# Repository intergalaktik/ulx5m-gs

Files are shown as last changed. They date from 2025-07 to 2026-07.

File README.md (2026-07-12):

# Work in progress!!! 

# Please use v005

# Please check the list of confirmed working

# DEFAULT VOLTAGE FOR GPIO IS SET TO 1.8V!!!

# DEFAULT SDRAM PART is 1.8V

# DEFAULT VCC CORE is 0.9V - if you use SerDes this needs to be higher

# Most of our tests are done with VCC CORE 1.1V 

# ULX5M-GS v005
ULX5M with GateMate with SDRAM

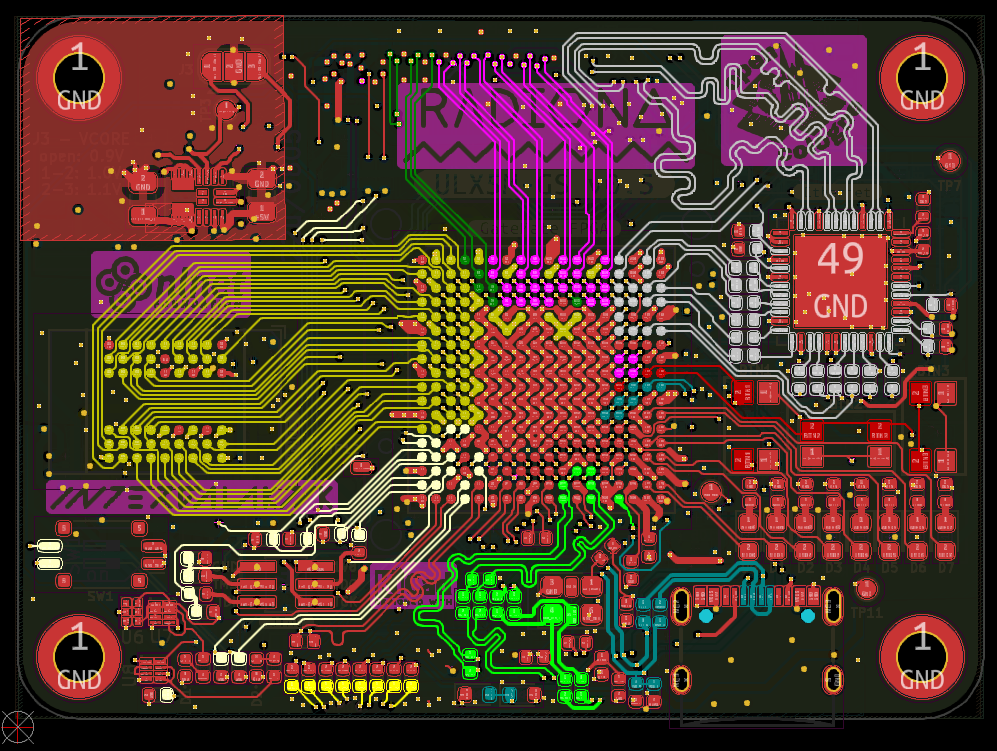
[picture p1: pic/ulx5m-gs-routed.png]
Layers_v001

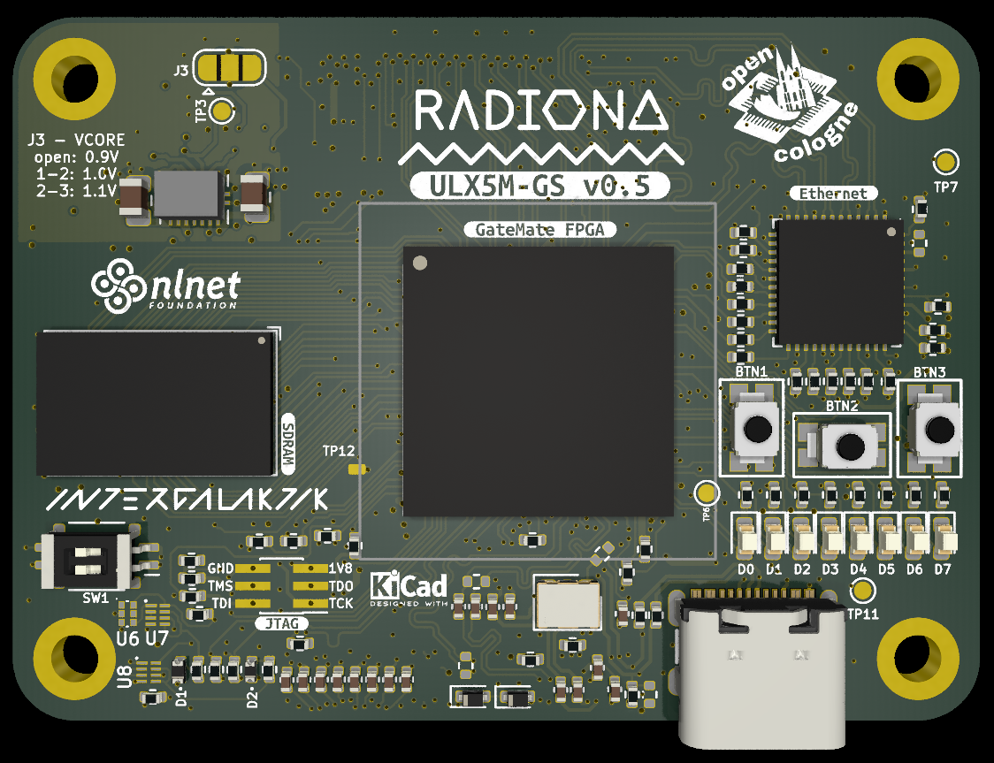
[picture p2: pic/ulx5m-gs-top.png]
TOP

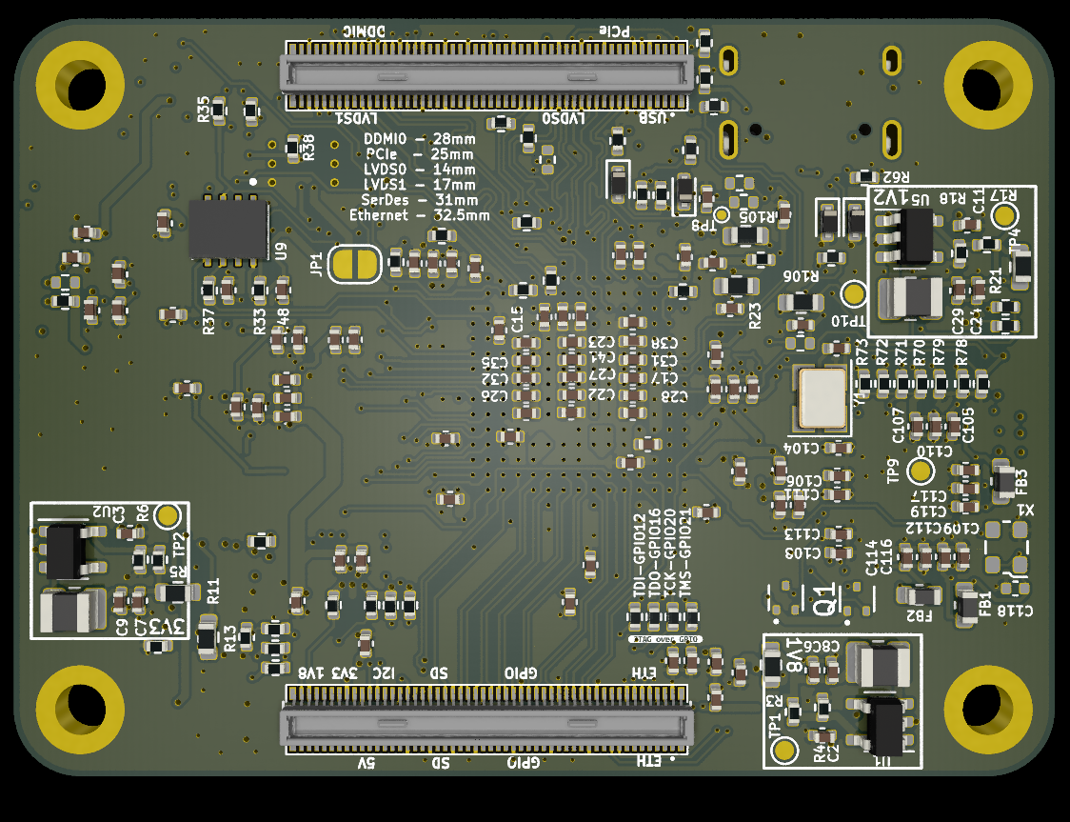
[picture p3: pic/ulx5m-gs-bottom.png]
BOTTOM


#### ULX5M-GS V001

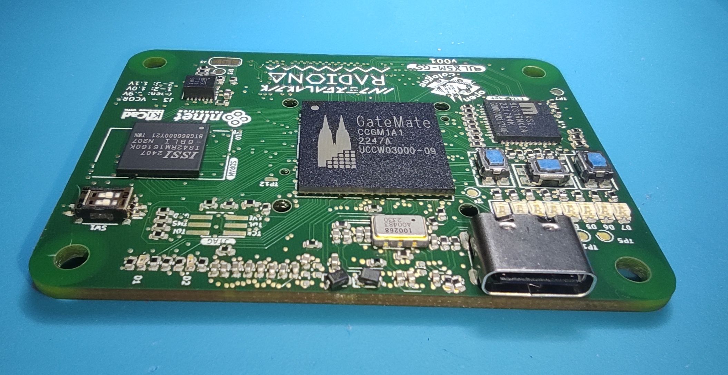
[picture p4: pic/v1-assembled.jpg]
Assembled


#### V001 LED ON

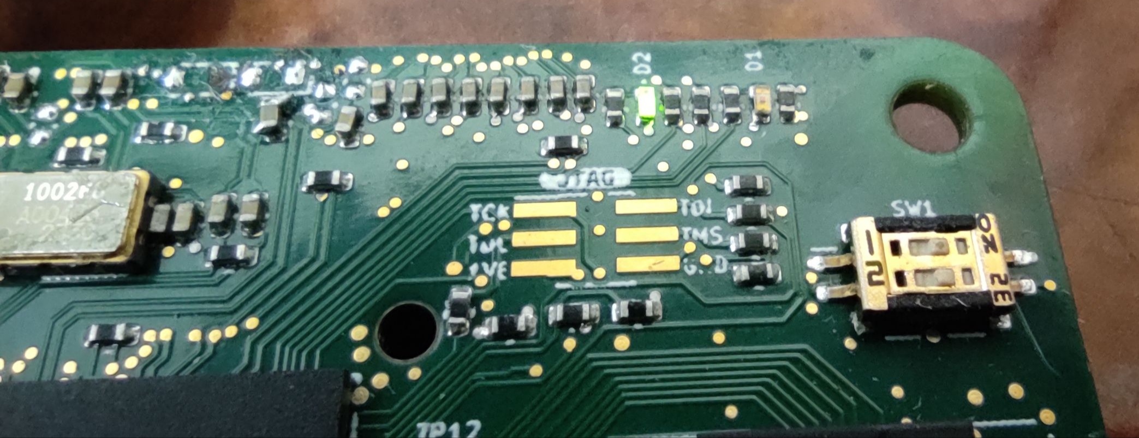
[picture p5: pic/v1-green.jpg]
Green


#### ULX5M-v02 bringup

#### Blink LED

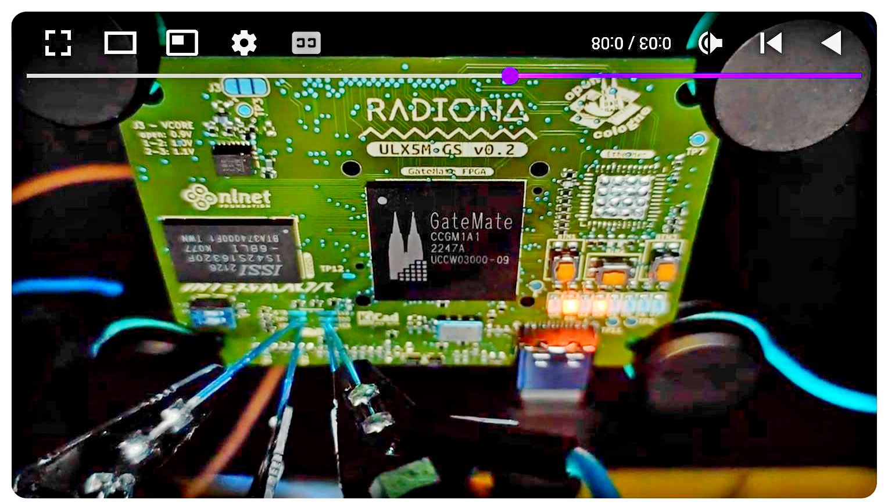
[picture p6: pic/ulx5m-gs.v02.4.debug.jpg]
ULX5M blinks LEDs on its own (https://www.youtube.com/watch?v=LA20pfW7X00 "ULX5M is counting!")


#### DVI OUT

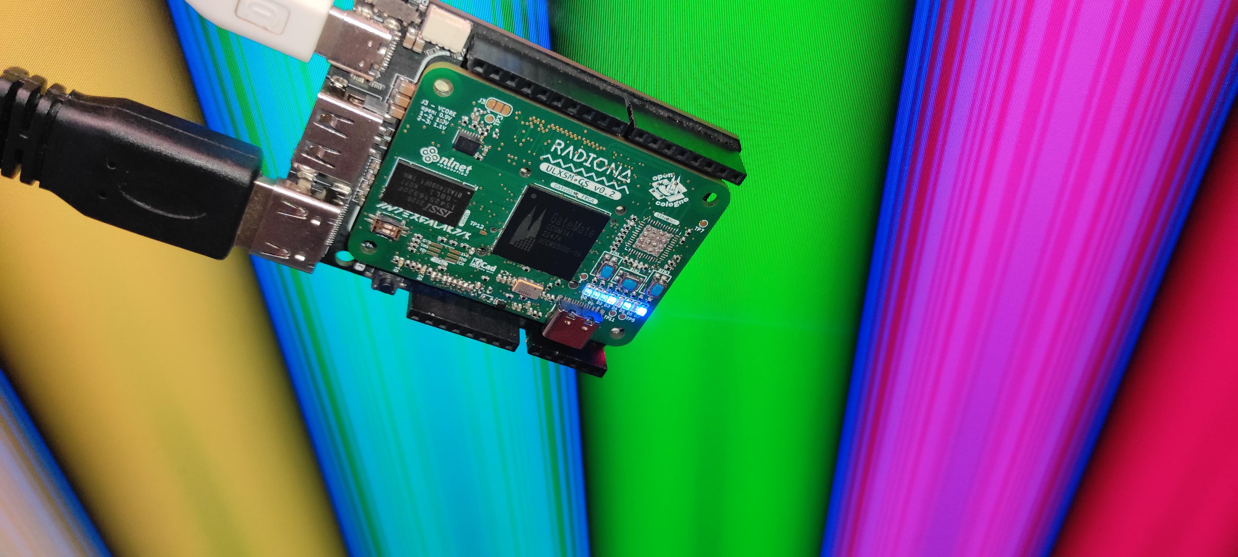
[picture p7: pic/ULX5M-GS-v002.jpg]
V002


#### SDRAM working with LiteX

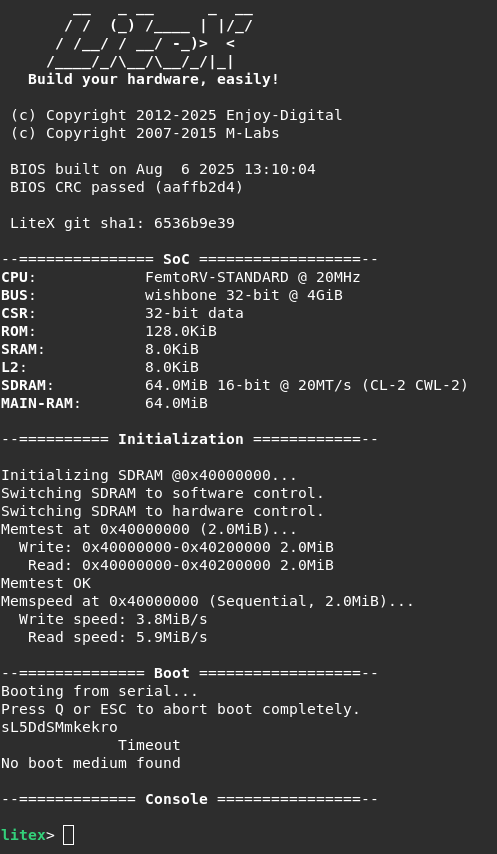
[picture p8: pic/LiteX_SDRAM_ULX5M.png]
V002 Litex


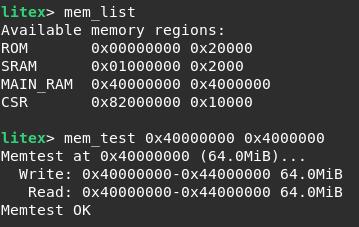
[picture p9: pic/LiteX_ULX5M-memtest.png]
V002 Litex full memtest


#### VGA over GPIO

While testing LVDS I wanted to check if we can have VGA over GPIO and it looks OK 

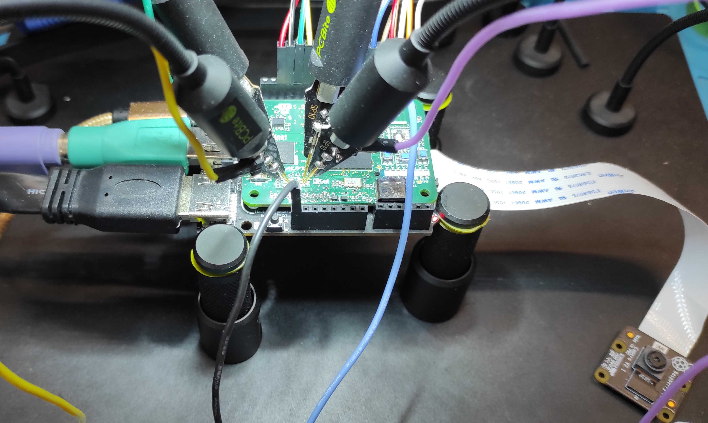
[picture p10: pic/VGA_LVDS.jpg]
V002 VGA


For now only possible over VGA

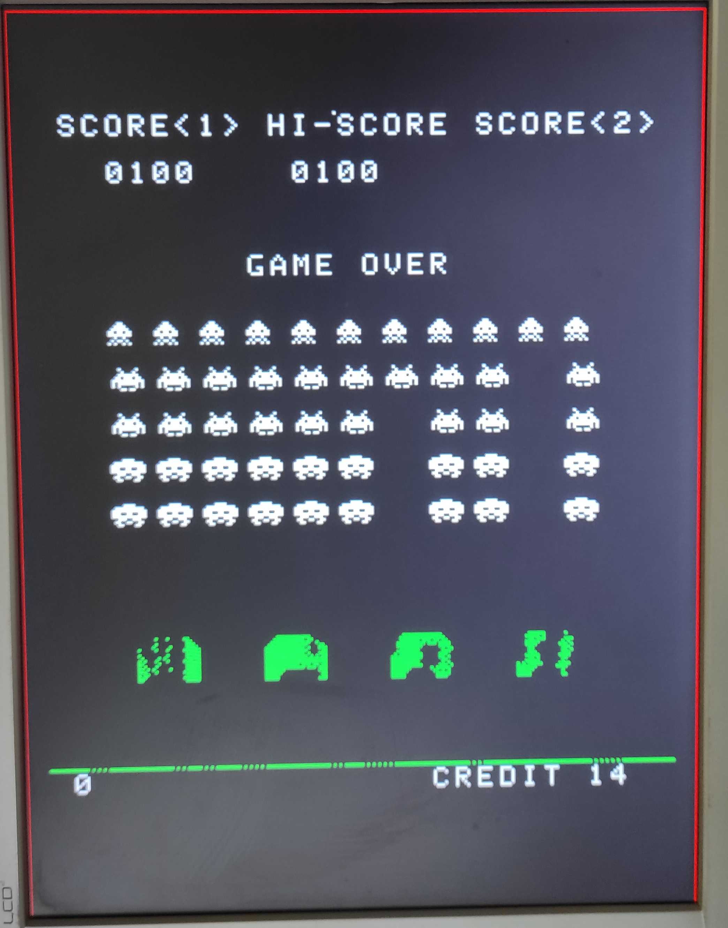
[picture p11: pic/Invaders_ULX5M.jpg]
V002 Invaders_VGA


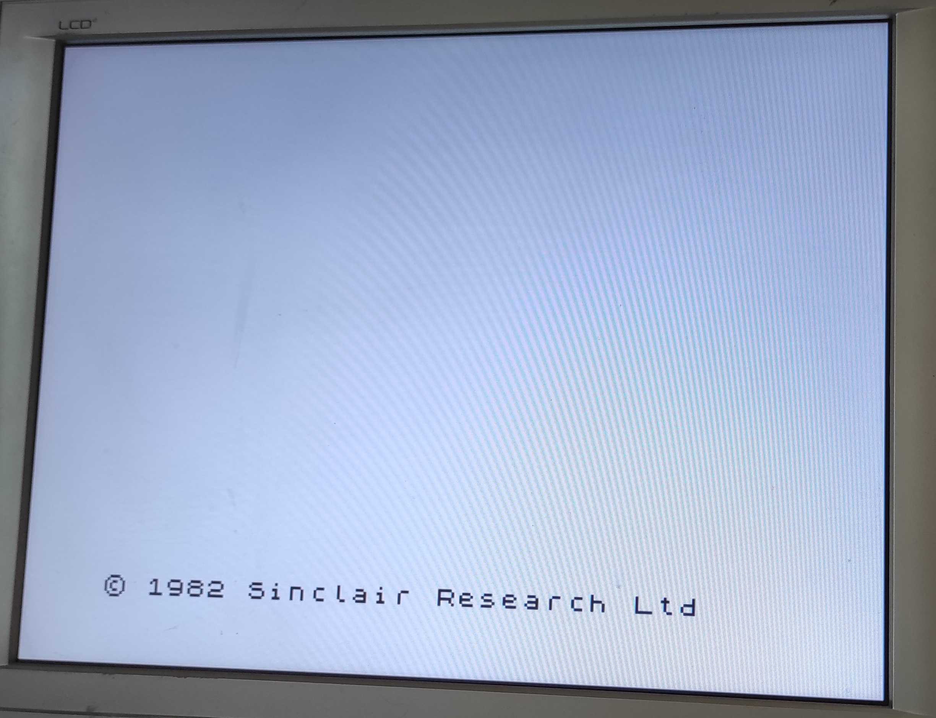
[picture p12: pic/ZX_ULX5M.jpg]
V002 ZX_VGA


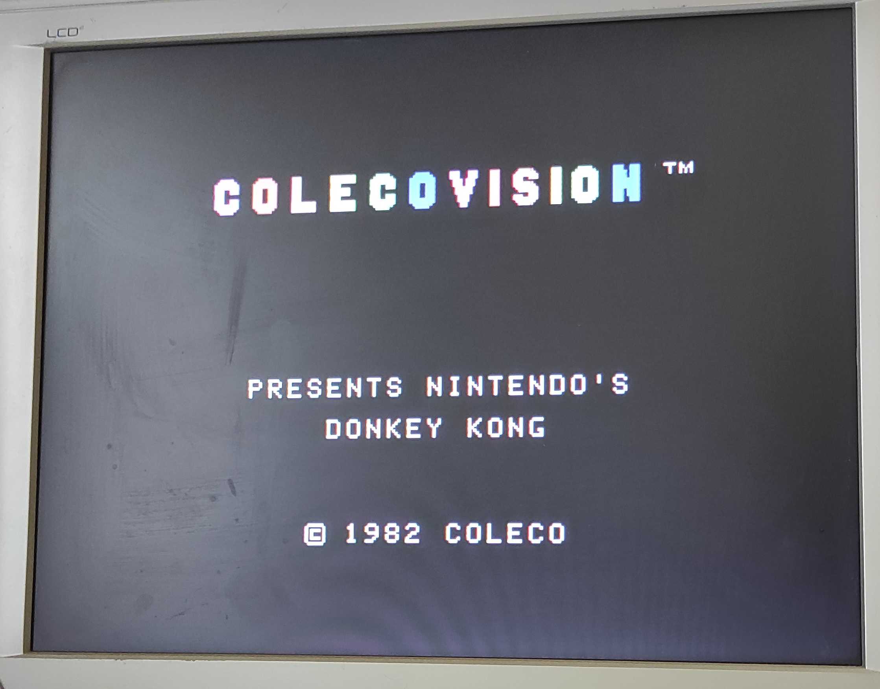
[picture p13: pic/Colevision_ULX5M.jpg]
V002 Colevision_VGA


* Power regulators
  * [MPM3833C](https://www.monolithicpower.com/en/mpm3833c.html) 0.9V..1.1V V_core, 3A
  * [TI62569](https://www.ti.com/lit/ds/symlink/tlv62569.pdf?ts=1709559273755) 1.2V, 1.8V, 2.5V, 3.3V V_io, 2A

* GateMate
  * compatibility to A1 - A2 is not tested
  * ext. clock: 100 MHz lvds (can be used for both serdes and pll)
  * ext. clock: 25MHz
  * programmer interface
  * usb-c connector
  * select between flash and jtag config (DIP switch)

* Gigabit Ethernet
  * KSZ9031RNXCA

* SDRAM 1V8/2.5V/3.3V selectable in production - default version is 1.8V

* Interfaces
  * [X] 8 LEDs ( 8 )
  * [X] 3 BTNs ( 3 )  
  * [X] SD Card (4 data lines)
  * [X] RPi 26 GPIO + 2 I2C GPIOs ( 12 diff pairs + 2 routed no diff )
  * [X] DDMI0 ( 3 diff data lines + diff clock )
  * [X] LVDS0 ( 4 diff data lines + diff clock )
  * [X] LVDS1 ( 3 diff data lines + diff clock )
  * [X] USB-C ( 1 diff data line + USBID )
  * [X] PCIe  ( 2 diff data lines + diff clock )
  * [X] SDRAM
  * [X] Gigabit Ethernet
  * [X] FLASH

 * Tested and confirmed working from V004 
  * [X] LEDs
  * [X] BTNs
  * [X] Video output ( DVI )
  * [X] GPIO output
  * [X] USB-C TinyDFU USB Bootloader
  * [X] Serial Over GPIO
  * [X] VGA Over GPIO
  * [X] JTAG
  * [X] LVDS - rapicam*
  * [X] DIP SW - they work as FLASH BOOT SELECT
  * [X] FLASH - I can put bitstream in flash and boot from flash
  * [X] SDRAM - tested and working with LiteX
  * [X] SD - tested and working with LiteX
  * [X] DVI - tested and works
  * [X] Ethernet - confirmed on v004 - v005 is not tested
  * [ ] PCIe (SerDes) - internal test works - externaly not tested
   
*LVDS I can get cam stream not to trow any error but without and output 
  if I add output cam trows errors - there are some timming issues in the core... 

## References

https://github.com/OLIMEX/GateMateA1-EVB

https://github.com/intergalaktik/Extension_Boards_for_Olimex_GateMate

https://github.com/YosysHQ/prjpeppercorn-test-cases

https://github.com/YosysHQ/prjpeppercorn
  
https://github.com/chili-chips-ba/openCologne

https://www.chili-chips.xyz/open-cologne

## Acknowledgements

This project was done in collaboration with Chili Chips*Ba team. 
They have put enormes effort in making all cores to work on GateMate even before we have our own board!
Thanks to them now we have big set of cores that can be used to check and improve opensource toolchain!
They are proven to be reliable partners that solves problem quickly and on side works on educating younger generations!

Also big thanks goes to YosysHQ as they are doing miracles with open source tooling, and we now finaly have one that works for GateMate!

From YosysHQ special thanks to Micko and Lofty that are helping in real time on Discord!

Special thanks to Patrick from Cologne, as without him and rest of Cologne team we would not be able to get this project done.

## Work on this board is financed by NLnet foundation

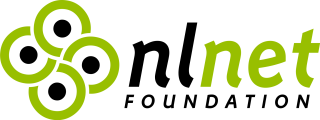
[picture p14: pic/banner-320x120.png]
NLnet


https://nlnet.nl/project/openCologne/

This project was funded through the NGI0 Entrust Fund, a fund established by NLnet with financial support from the European Commission's Next Generation Internet programme, under the aegis of DG Communications Networks, Content and Technology under grant agreement No 101069594.

## Check up our blogposts
Comming soon!!!

## Contact us

Discord: https://discord.gg/qwMUk6W

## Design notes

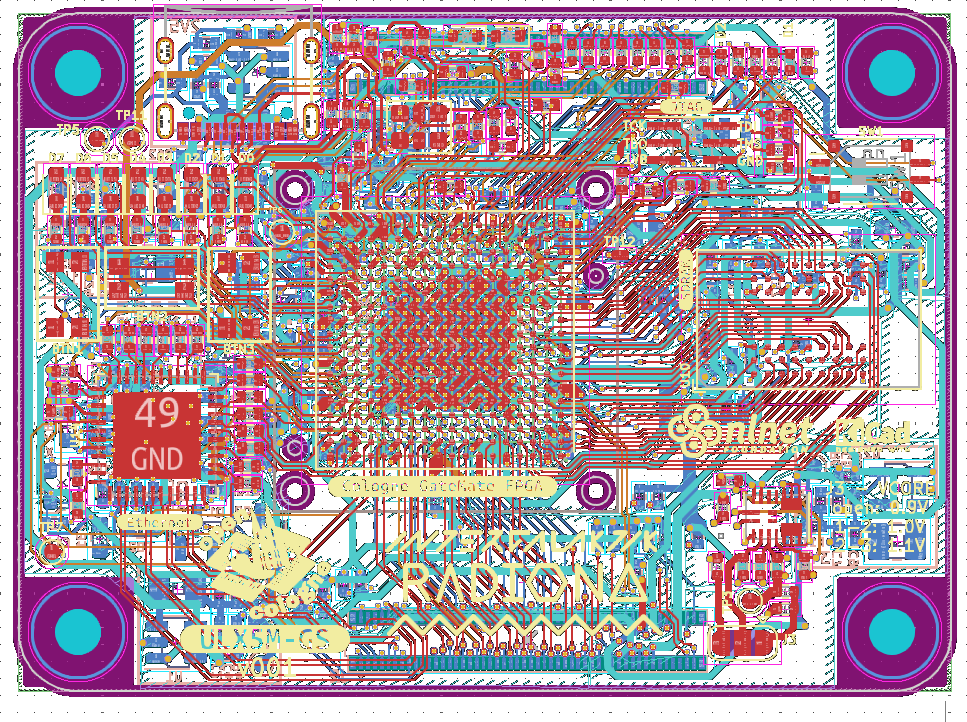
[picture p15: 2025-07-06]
pic/ulx5m-gs-routed_v002.png

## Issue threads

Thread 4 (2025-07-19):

Some parts are wrong in BOM - needs update

goran-mahovlic, 2025-07-19:
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

goran-mahovlic, 2025-08-04:
Fixed 25MHZ clock

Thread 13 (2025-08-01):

USB did not work with TXS0202YZPR

goran-mahovlic, 2025-08-01:
I think that A and B side are maybe switched.
I have removed that chip from prototype and connected diff lines directly and got USB bootloader to enumerate

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

Closed 2025-08-04.

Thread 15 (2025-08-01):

We could connect SerDes pins of A2 to USB3 on CM5 fast connector

goran-mahovlic, 2025-08-01:

goran-mahovlic, 2025-08-04:
Currently not possible - I would need to switch to 8L board to have that port connected - so I will leave this one for later. We now have confirmation that our PCIe project got the grant so we may also need to modify PCIe lines and that could also be impossible without switching to 8L board...

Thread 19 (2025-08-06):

It could be that internal PULL DOWN is not working on BTN

goran-mahovlic, 2025-08-06:
We have noticed strange connection between BTN1 and BTN2 - they are not connected in any way when board is off - but in design they act like they are. So on v003 we will go with external PULL UPs and invert button logic

Closed 2025-08-07.

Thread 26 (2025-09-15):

`CFG_DONE` / `CFG_FAILED_N` latch logic missing

pu-cc, 2025-09-15:
I strongly recommend latching both signals `CFG_DONE` and `CFG_FAILED_N`. They may have a different function after switching the configuration bank in user mode. `CFG_FAILED_N` is furthermore only a pulse.

My suggestion: use a dual 2-input NAND and a single inverter to create a latch. Components with a small footprint include, for example: `74LVC2G00HK3-7` or `74LVC2G00GT,115`

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

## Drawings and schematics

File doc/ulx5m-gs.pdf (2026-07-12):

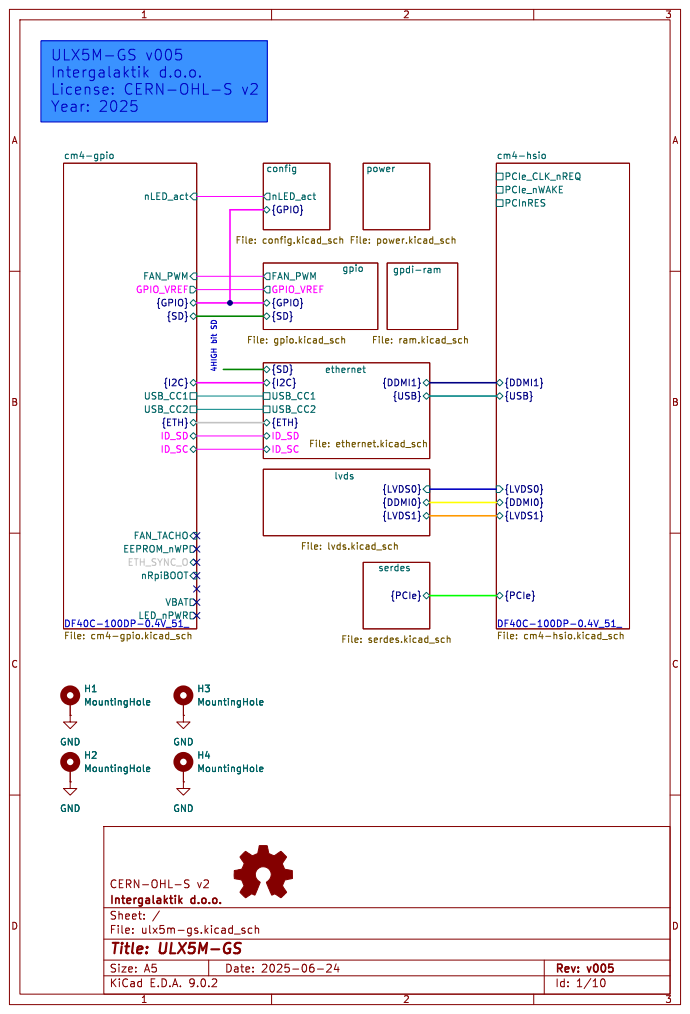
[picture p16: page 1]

File: ram.kicad_sch H4 MountingHole GND

{PCIe} serdes File: serdes.kicad_sch

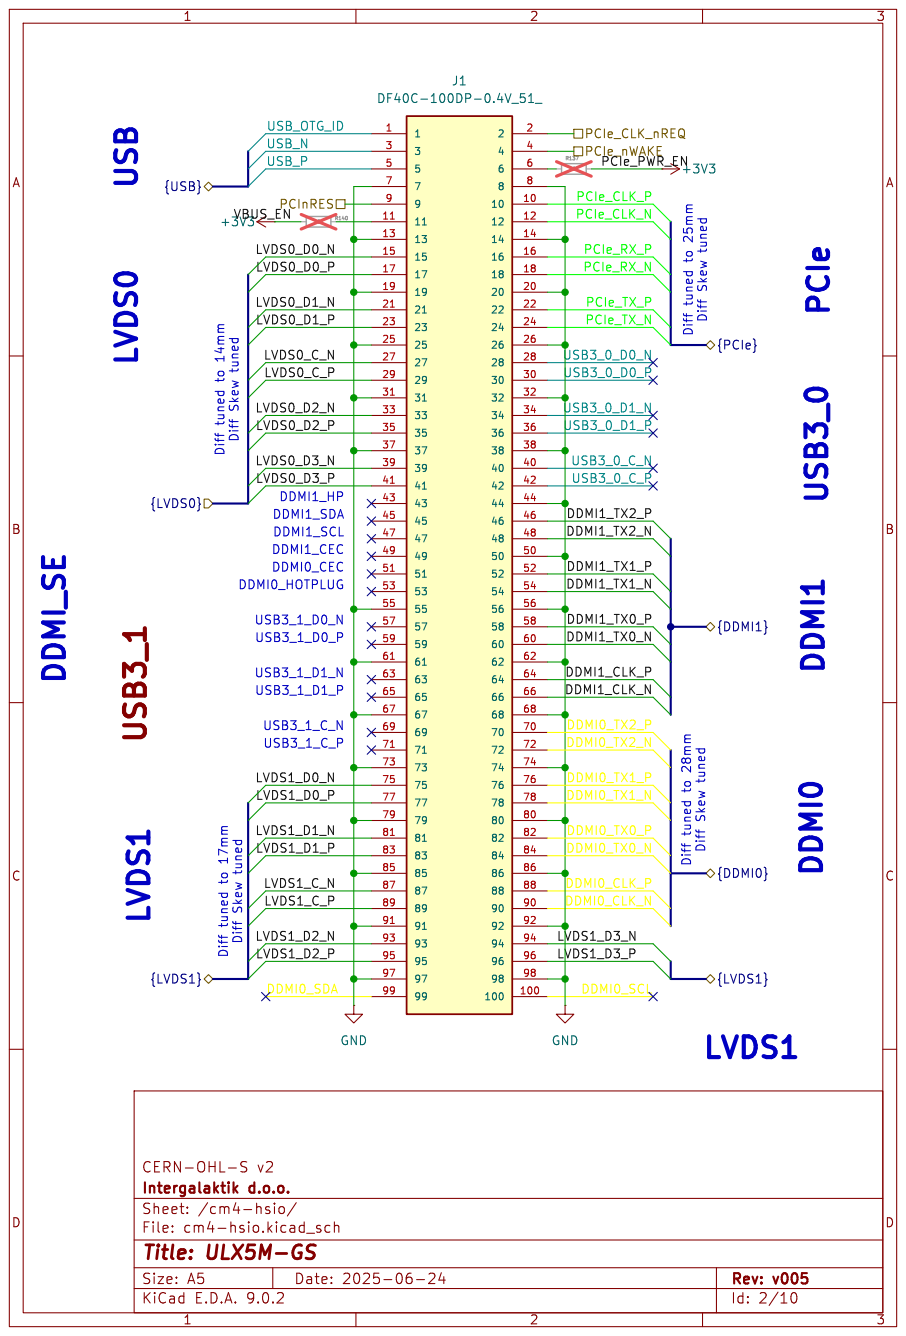
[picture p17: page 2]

File: cm4-hsio.kicad_sch Sheet: /cm4-hsio/
Id: 2/10 Title: ULX5M-GS

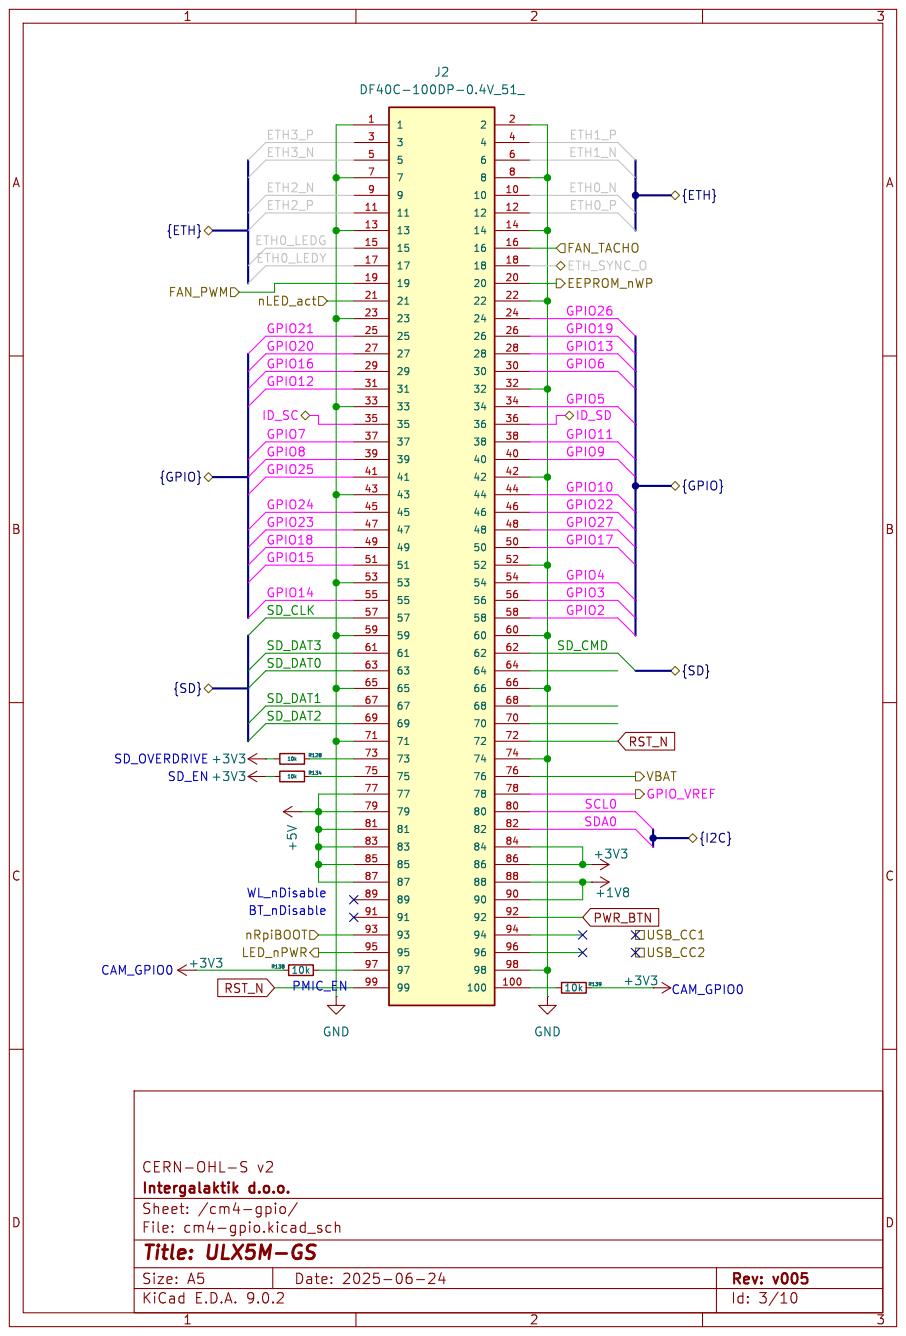
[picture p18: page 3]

File: cm4-gpio.kicad_sch Sheet: /cm4-gpio/
Id: 3/10 Title: ULX5M-GS

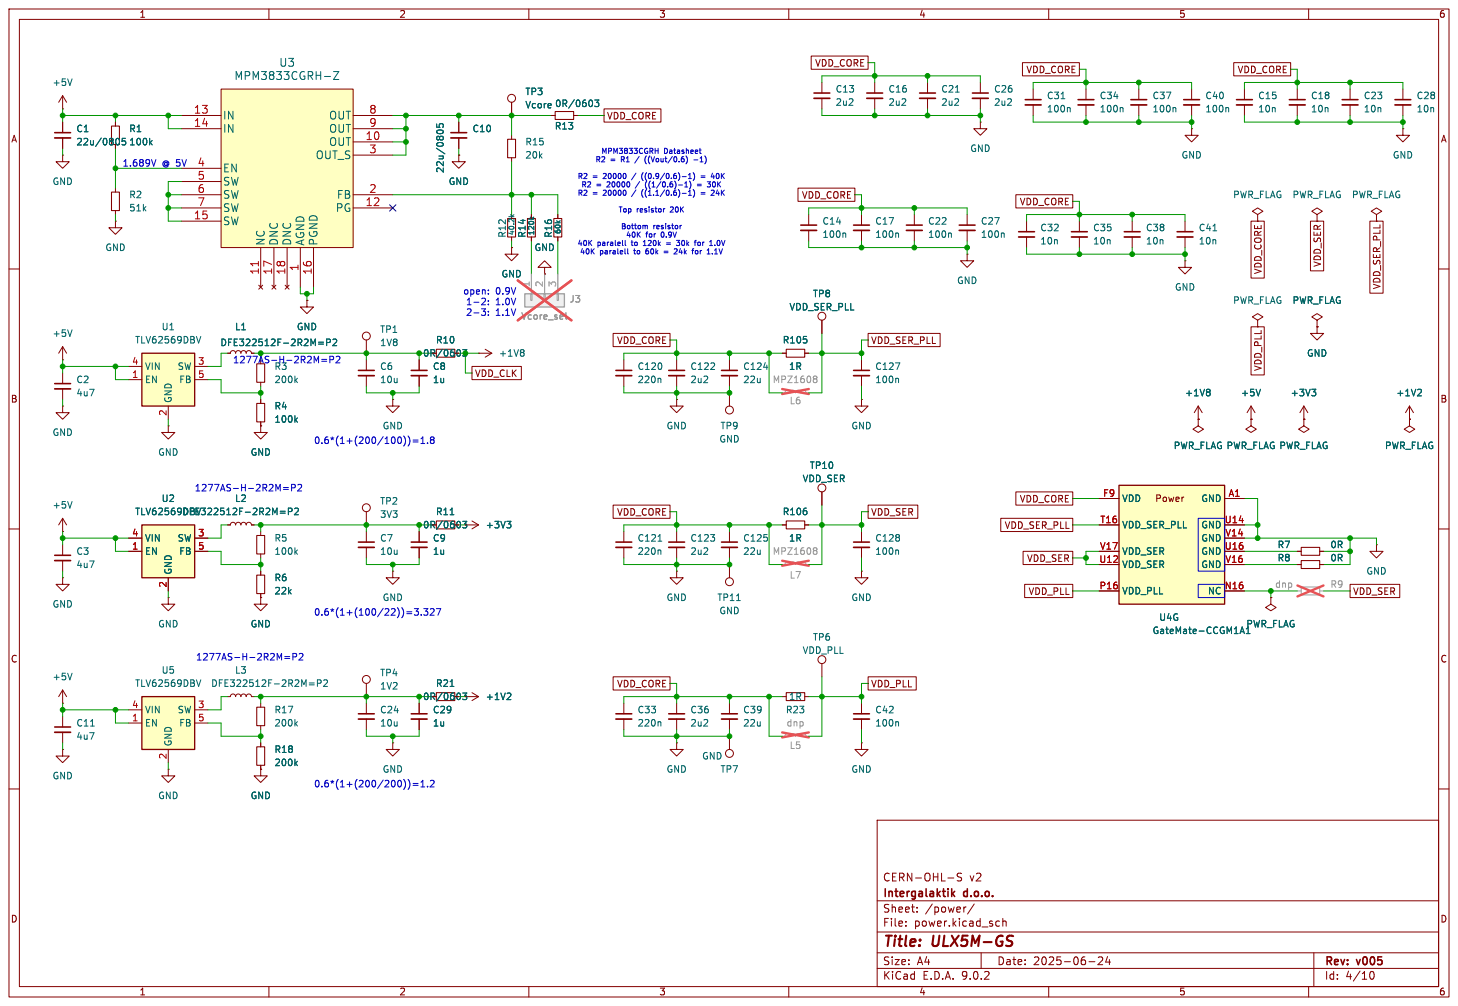
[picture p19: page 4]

1 PGND 16 OUT 8 OUT 9 OUT 10 OUT_S 3 FB 2 PG 12 U3 MPM3833CGRH-Z

File: power.kicad_sch Sheet: /power/
Id: 4/10 Title: ULX5M-GS

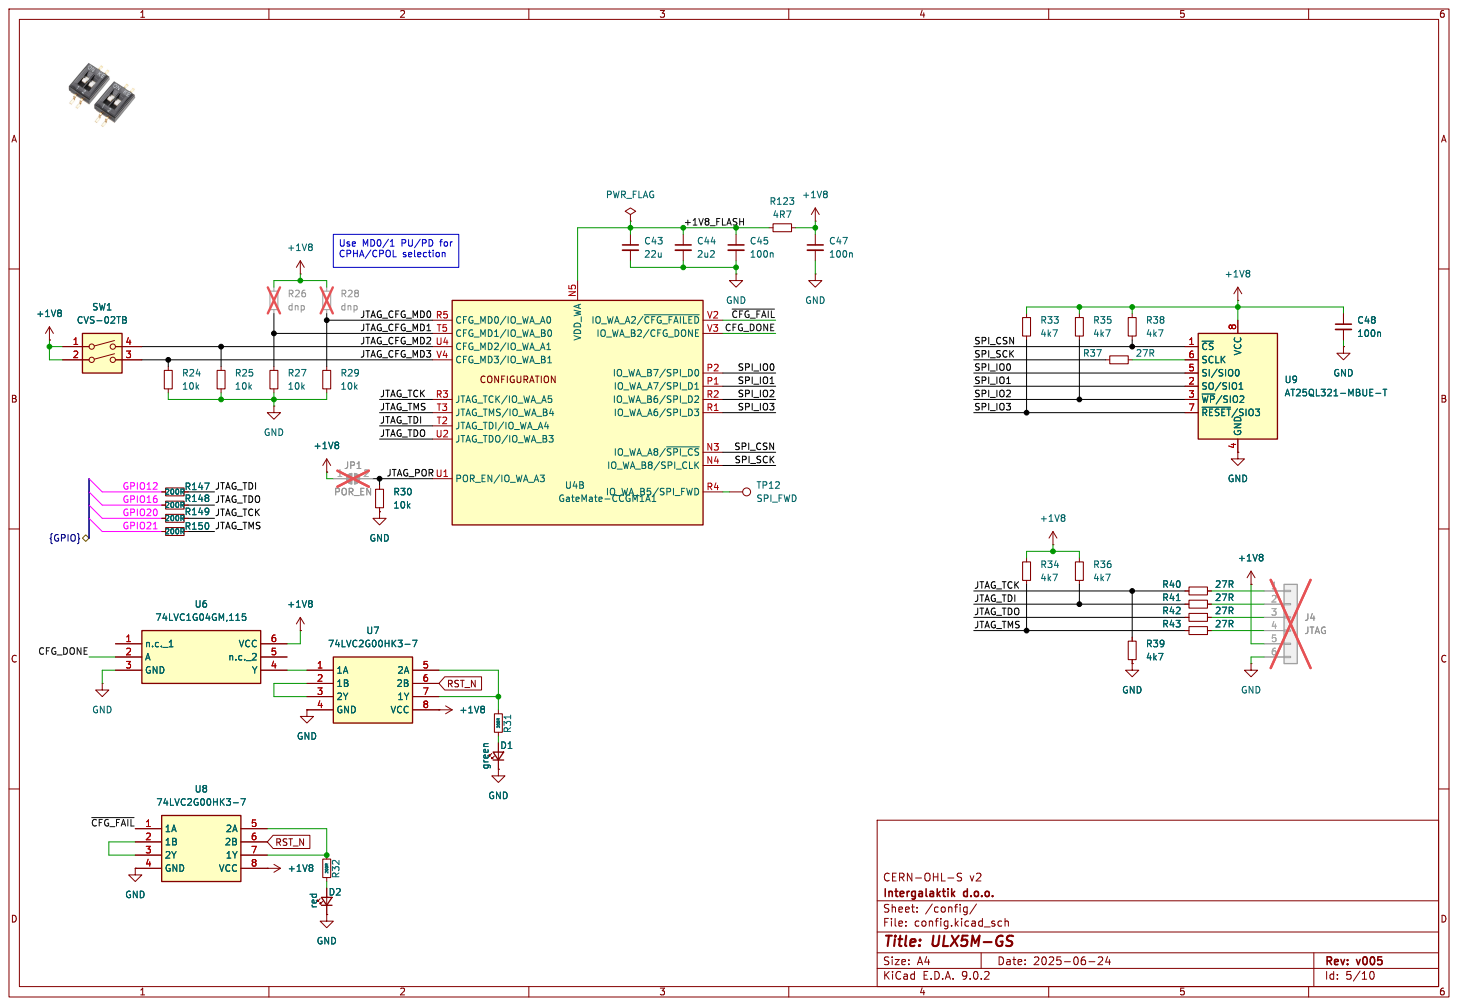
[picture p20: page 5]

File: config.kicad_sch Sheet: /config/
Id: 5/10 Title: ULX5M-GS

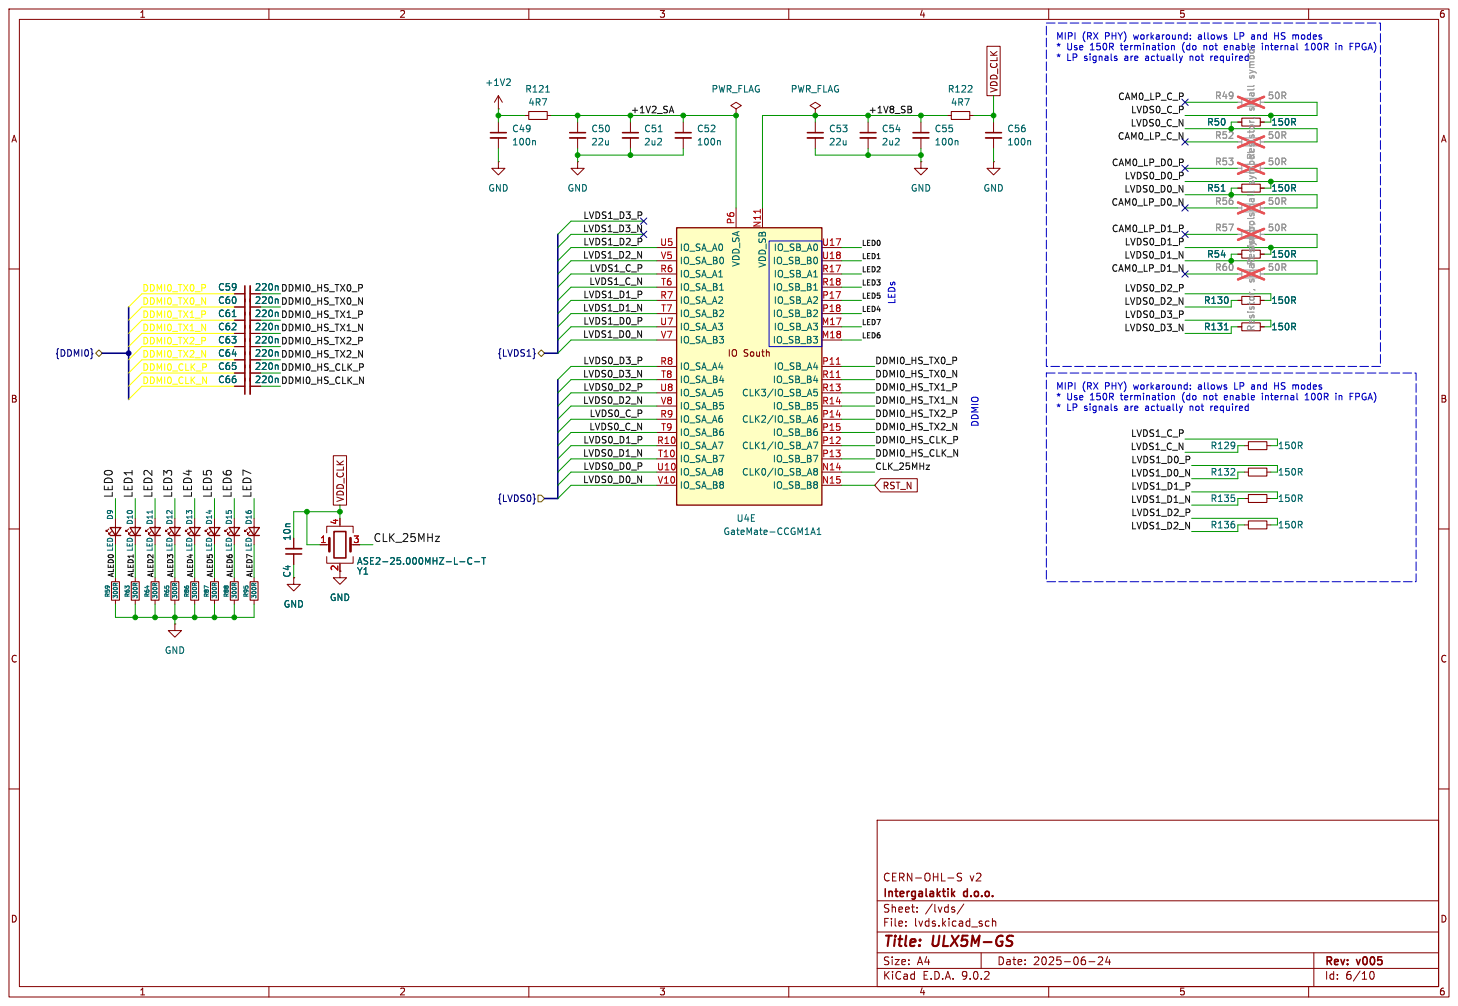
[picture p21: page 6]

File: lvds.kicad_sch Sheet: /lvds/
Id: 6/10 Title: ULX5M-GS

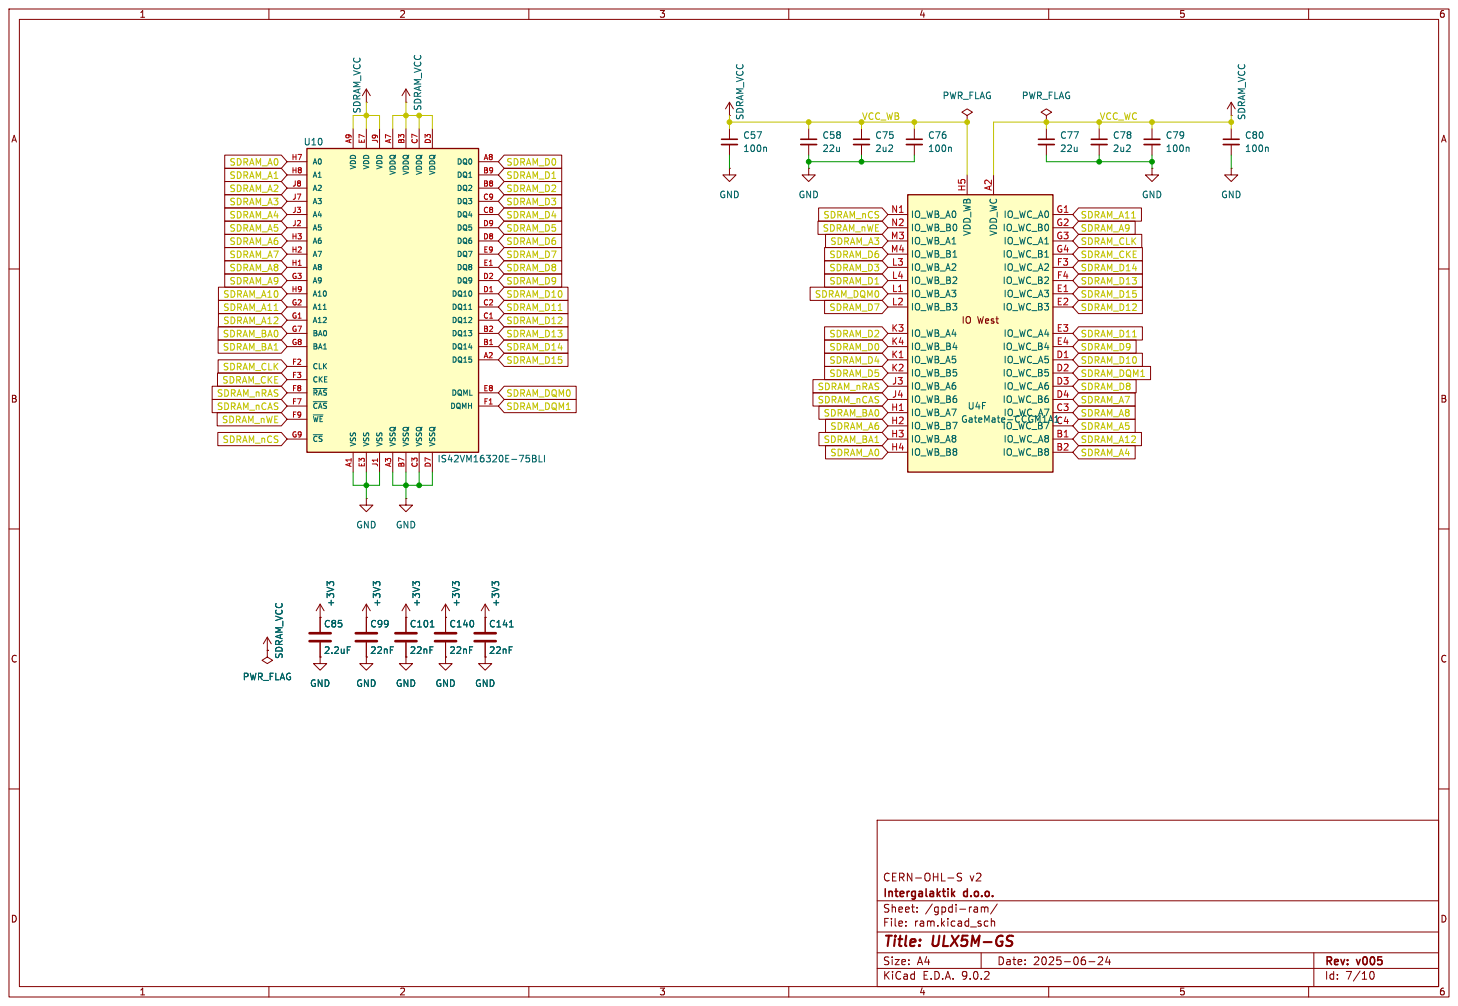
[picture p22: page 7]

File: ram.kicad_sch Sheet: /gpdi-ram/
Id: 7/10 Title: ULX5M-GS

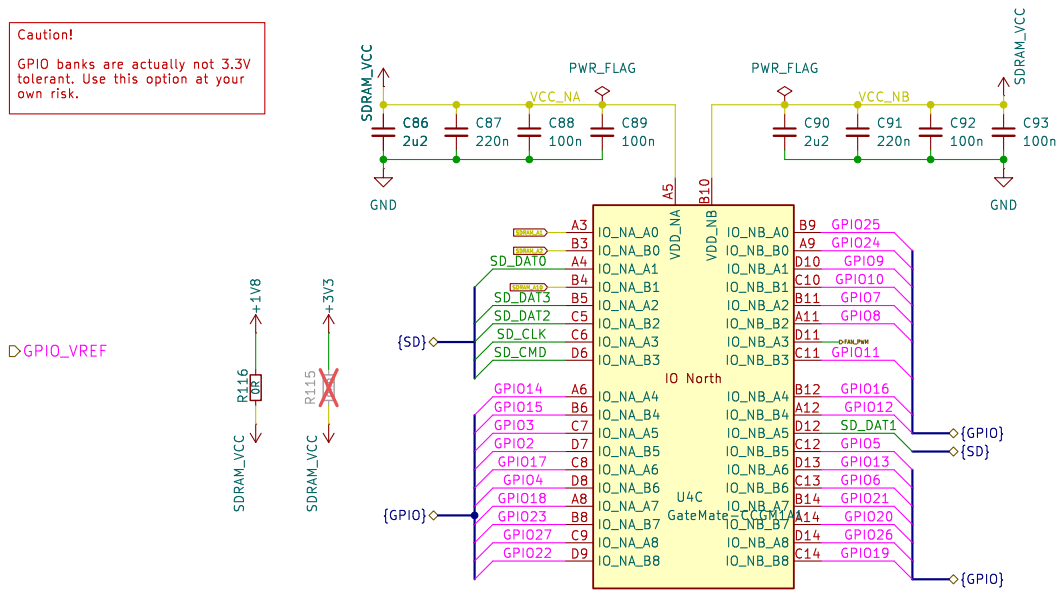
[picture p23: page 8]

File: gpio.kicad_sch Sheet: /gpio/
Id: 8/10 Title: ULX5M-GS

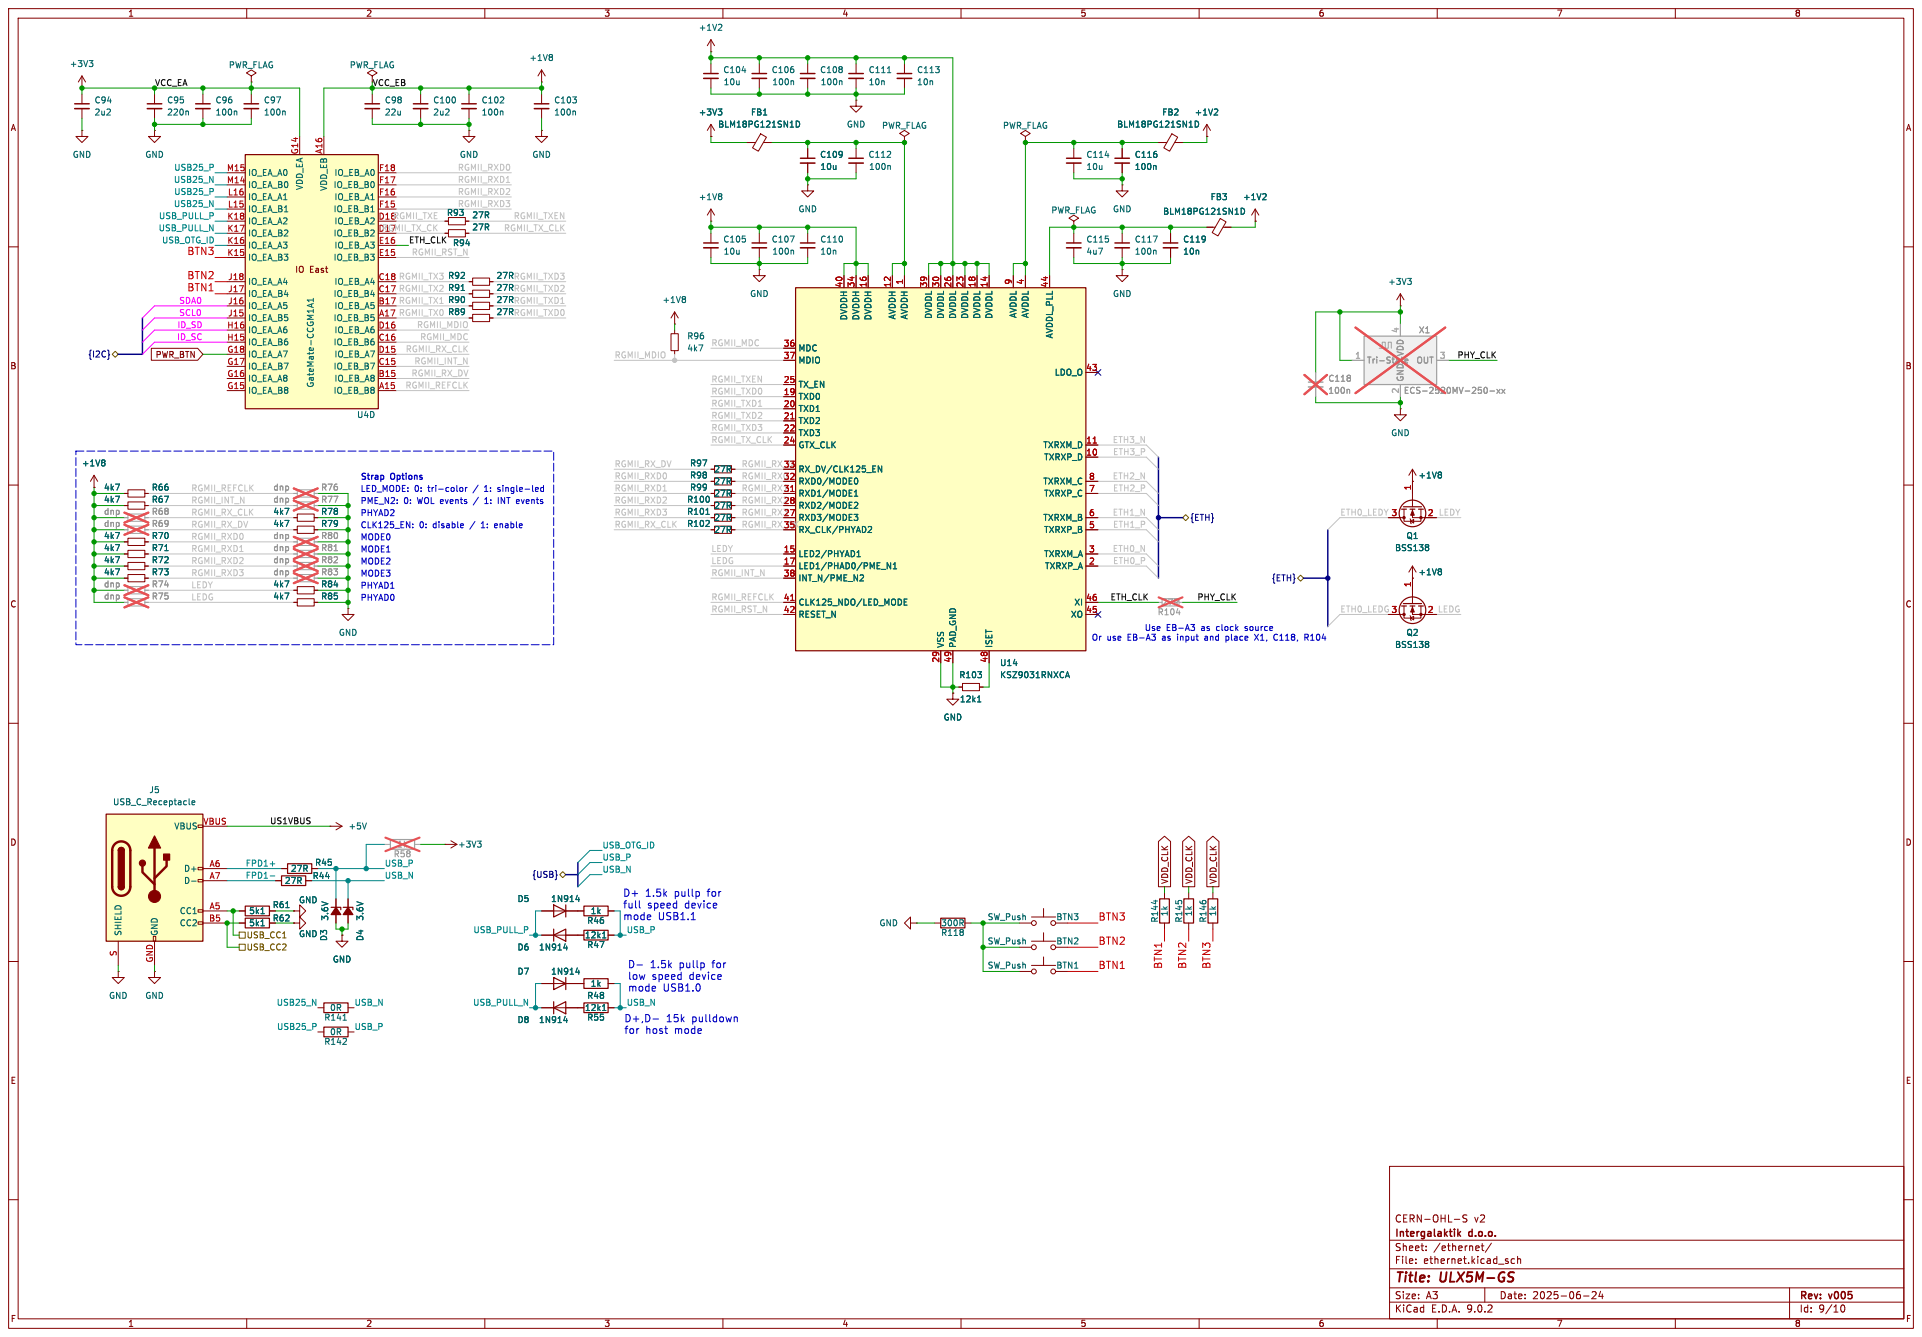
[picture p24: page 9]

1 DVDDL 39 DVDDL 30 VSS 29 DVDDL 26 PAD_GND 49 DVDDL 23 DVDDL 18 DVDDL 14 ISET 48 AVDDL
LDO_O 43 TXRXM_D 11 TXRXP_D 10 TXRXM_C 8 TXRXP_C 7 TXRXM_B 6 TXRXP_B 5 TXRXM_A 3 TXRXP_A 2 XI 46 XO 45 U14 KSZ9031RNXCA

full speed device mode USB1.1 D- 1.5k pullp for

low speed device mode USB1.0

File: ethernet.kicad_sch Sheet: /ethernet/
Id: 9/10 Title: ULX5M-GS

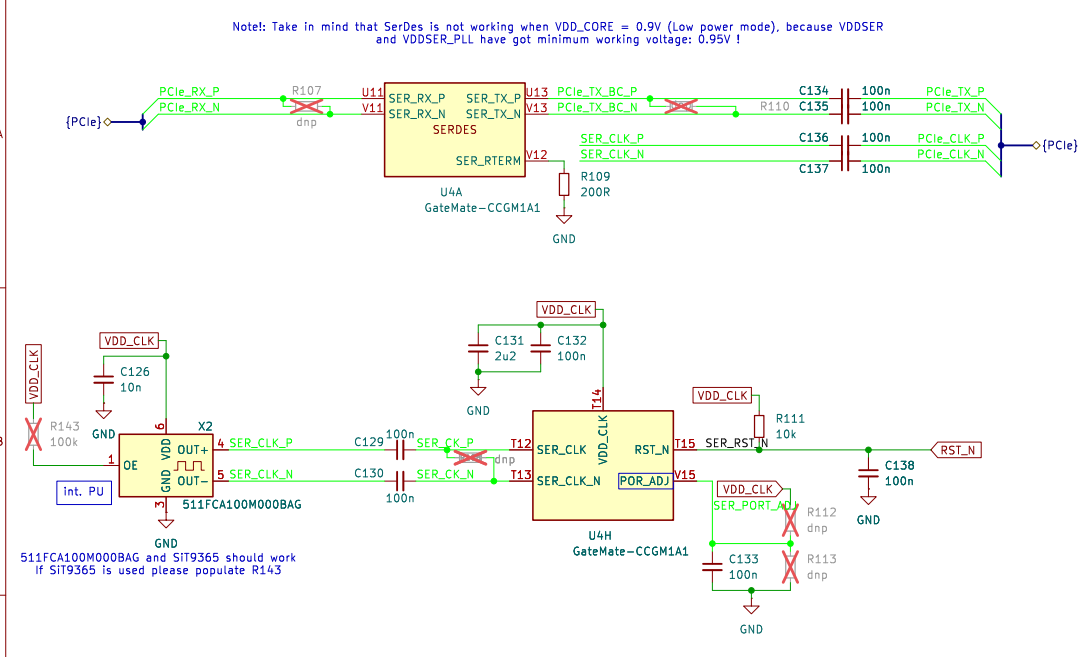
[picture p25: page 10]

Note!: Take in mind that SerDes is not working when VDD_CORE = 0.9V (Low power mode), because VDDSER

3 OUT+ 4 OUT- 5 GND GND

File: serdes.kicad_sch Sheet: /serdes/
Id: 10/10 Title: ULX5M-GS

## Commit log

2025-04-01 Adding initial designs started by Patrick
    [bom-prices.ods, cm4-gpio.kicad_sch, cm4-hsio.kicad_sch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]
2025-04-07 Adding Olimex fanout without Caps
    [ulx5m-gs.kicad_pcb]
2025-04-07 Moving to 6layer - importing rules
    [ulx5m-gs.kicad_pcb]
2025-04-16 Adding SDRAM - missing 3 pins
    [cm4-gpio.kicad_sch, cm4-hsio.kicad_sch, config.kicad_sch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]
2025-04-16 Using high SDcard pins for SDRAM
    [config.kicad_sch, gpio.kicad_sch, ram.kicad_sch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]
2025-04-17 PCB - sorting power supplys
    [config.kicad_sch, power.kicad_sch, ram.kicad_sch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]
2025-04-22 Sorting ethernet
    [ethernet.kicad_sch, ulx5m-gs.kicad_pcb]
2025-04-22 Placing caps bellow FPGA
    [config.kicad_sch, power.kicad_sch, ulx5m-gs.kicad_pcb]
2025-05-08 Adding USB connector and level converter
    [cm4-hsio.kicad_sch, config.kicad_sch, ethernet.kicad_sch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]
2025-06-23 Connecting USB
    [config.kicad_sch, ethernet.kicad_sch, ulx5m-gs.kicad_pcb]
2025-06-24 Routing diff clock
    [cm4-gpio.kicad_sch, cm4-hsio.kicad_sch, config.kicad_sch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]
2025-06-24 Adding LEDs
    [mipi.kicad_sch, ulx5m-gs.kicad_pcb]
2025-06-24 Adding Switches and 25MHz oscilator
    [config.kicad_sch, mipi.kicad_sch, ulx5m-gs.kicad_pcb]
2025-06-30 Before resistor move
    [ulx5m-gs.kicad_pcb]
2025-06-30 Clearing errors
    [config.kicad_sch, ethernet.kicad_sch, gpio.kicad_sch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]
2025-06-30 Adding more VIAs
    [mipi.kicad_sch, ulx5m-gs.kicad_pcb]
2025-07-01 Routing GPIO
    [cm4-gpio.kicad_sch, config.kicad_sch, gpio.kicad_sch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]
2025-07-01 Placing CAPS routing
    [ulx5m-gs.kicad_pcb]
2025-07-02 routing PCIe
    [config.kicad_sch, serdes.kicad_sch, ulx5m-gs.kicad_pcb]
2025-07-02 Updat to CM5
    [cm4-gpio.kicad_sch, cm4-hsio.kicad_sch, ethernet.kicad_sch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]
2025-07-03 Routing GPDI
    [cm4-gpio.kicad_sch, config.kicad_sch, ethernet.kicad_sch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]
2025-07-03 Clearing ERC errors/warnings
    [cm4-gpio.kicad_sch, cm4-hsio.kicad_sch, config.kicad_sch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]
2025-07-03 Sync PCB
    [ulx5m-gs.kicad_pcb]
2025-07-03 Clearing all ERC, rounting diff
    [cm4-hsio.kicad_sch, config.kicad_sch, ethernet.kicad_sch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]
2025-07-03 initail routing of all differential pins
    [ulx5m-gs.kicad_pcb]
2025-07-03 Routing BTNs, LEDs, CLK
    [cm4-gpio.kicad_sch, config.kicad_sch, ethernet.kicad_sch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]
2025-07-04 Adding schematics
    [config.kicad_sch, ulx5m-gs.kicad_pcb]
2025-07-06 5 more power lines are missing routes
    [ulx5m-gs.kicad_pcb]
2025-07-06 Routing completed!
    [ulx5m-gs.kicad_pcb]
2025-07-06 Improving power layer
    [ulx5m-gs.kicad_pcb]
2025-07-06 Adding logos
    [config.kicad_sch]
2025-07-08 Adding L1, L2, L3, L4 FB1,FB2, FB3 parts, changing name under FPGA
    [config.kicad_sch, ethernet.kicad_sch, power.kicad_sch]
2025-07-10 GPIO are now routed differential
    [cm4-hsio.kicad_sch, config.kicad_sch, ethernet.kicad_sch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]
2025-07-19 Adding pictures of assembled v1
2025-08-04 Changing FLASH footprint - fix #7 fix #8
    [config.kicad_sch]
2025-08-04 Switching A and B on TXS0202YZPR adding pass resistors
    [ethernet.kicad_sch, power.kicad_sch, ulx5m-gs.kicad_sch]
2025-08-04 Adding PullUP to OE on SerDes CLK - also moved so it can be placed
    [serdes.kicad_sch]
2025-08-04 Fixing button voltage - fix #6
    [ethernet.kicad_sch]
2025-08-04 fix #1 by renaming - no real change was done
    [ram.kicad_sch]
2025-08-04 #2 should be cleared now
    [power.kicad_sch]
2025-08-04 Connecting PWR and FAN_PWM to NC pins, using NC3 for Ethernet clock
    [config.kicad_sch, ethernet.kicad_sch, gpio.kicad_sch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]
2025-08-04 Updating sch - moving power select resistors to bottom
    [cm4-hsio.kicad_sch, config.kicad_sch, ethernet.kicad_sch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]
2025-08-04 USB PULL resistors can now be 12K
    [ethernet.kicad_sch]
2025-08-04 Adding some tekst
    [lvds.kicad_sch]
2025-08-07 Fix #19
    [ethernet.kicad_sch]
2025-08-07 Adding more colors
    [ulx5m-gs.kicad_sch]
2025-08-08 Tuning LVDS0, LVDS1, DDMIO
    [cm4-hsio.kicad_sch]
2025-08-08 SerDes routing improvements
    [cm4-hsio.kicad_sch]
2025-08-15 Adding JTAG over GPIO
    [config.kicad_sch, ulx5m-gs.kicad_sch]
2025-09-30 Fix #23 added DNP to L, R changed to 1R, All power resistors moved to 0603
    [power.kicad_sch]
2025-09-30 #26 Added to schematics and PCB but not connected, placed, routed
    [config.kicad_sch]
2025-09-30 Moving VCC_EA to 3.3V - USB and GPIO #27
    [ethernet.kicad_sch]
2025-09-30 Removing USB voltage tranalstion as now bank is on 3.3V #27
    [ethernet.kicad_sch]
2025-09-30 Moving VDD_CLK to 1V8, removing 2V5
    [lvds.kicad_sch, power.kicad_sch, serdes.kicad_sch]
2025-09-30 Moving VDD_CLK to 1V8, removing 2V5 Fix #27
    [gpio.kicad_sch]
2026-03-13 Adding v004 schematics
2026-07-12 Improve SerDes routing, tunning ETH pairs, moving parts - fix #31
    [cm4-gpio.kicad_sch, cm4-hsio.kicad_sch, config.kicad_sch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]
2026-08-20 Adding fiducials
    [ulx5m-gs.kicad_pcb, ulx5m-gs.kicad_sch]
